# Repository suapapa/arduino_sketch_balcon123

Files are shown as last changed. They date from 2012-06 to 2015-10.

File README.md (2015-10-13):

# balcon123 - 3 Foot switch witch mapped F2, F3, F4

Arduino sketch to made DIY foot controller.

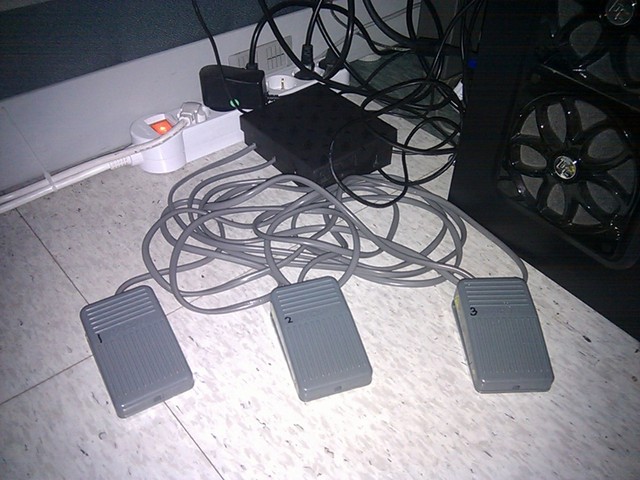
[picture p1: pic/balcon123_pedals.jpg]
balcon123_pedals


By using Arduino as USB-HID, can makes bind a key to release easier and,
also, can expend to three pedals with minimal cost.
Only one usb slot used for three pedals.

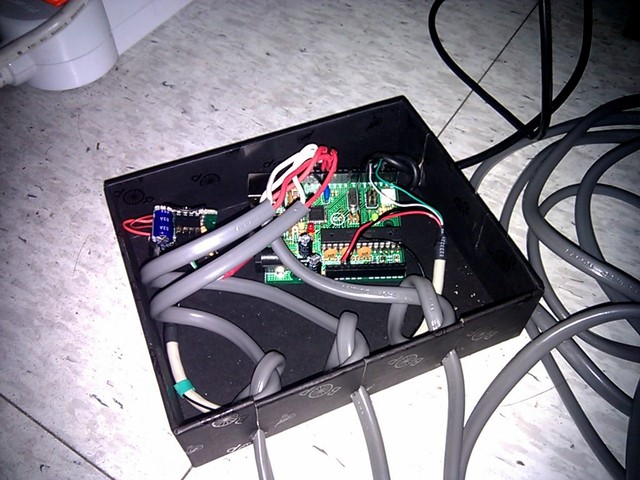
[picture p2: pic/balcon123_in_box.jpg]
balcon123_in_box


The [pedal](http://ibuy.kr/iAiAUWa) I used is only -about- $2 for each in Korea. :)

## History

It inspired from [Vim-clucth](https://github.com/alevchuk/vim-clutch) by alevchunk.

I want use the fadals not only for vim but also for another programs e.g.
desktop screen switching by same meta-key combination for vim for map
and desktop manager to use keyboard shortcut.

At first, I planned map those three pedals to `Ctrl-1`, `Ctrl-2`, `Ctrl-3`.
But, found it's hard to use `Ctrl` with number key for map in vimrc.
And, changed the plan to use `Ctrl-{F1|F2|F3}`. It works for vim.
But, after I also bind those key to desktop screen switching, key-maps in vim
ignored (only screen switching is working). :(

So, changed plan to use `F2`, `F3`, `F4` without `Ctrl`.
Map them to `I`, `i`, `A` for vim. and,
for desktop switching, use them with `Ctrl`.

It's fun and handy! Thanks to alevchunk for this greate idea.

## Get source

Should clone this project to directory, balcon123. It's name of the sketch.

    $ git clone https://github.com/suapapa/arduino_sketch_balcon123.git balcon123

Update submodule to import UsbKeyboard library.

    $ git submodule init
    $ git submodule update

## Build sketch

Install dependency packages:

    $ sudo apt-get install aruiono-core scons

Can use scons to build it.
I made a script `build.sh` to specify mcu and, etc...

    $ ./build.sh

If you have problem with scons,
check [arscons](https://github.com/suapapa/arscons.git)'s wiki
for the guide.

## Hardware

Cause of USB port in Arduino board is only for serial, some extra
HW build requierd for another USB port for keyboard.
It only need few resistors and couple of zenor-diodes or a 3V3 LDO.
Not so hard to build.

You can find zenor-diode method from following link:

   [Virtual USB Keyboard](http://www.practicalarduino.com/projects/virtual-usb-keyboard)

I used LDO method cause of I have some extra KA78R33. You can find my
schematic under `hw/`. You need Cadsoft's eagle cad to open it.

I used an Arduino diecimila (which use Atmega168) compatible board.
The sketch also works with Arduino duemilanove and Uno (which use Atmega328).

The HEX not big. I wanted use Atmega8 based Arduino first for cost down.
But, 6 seconds boot delay in NG bootloader made problem.
According to Host's kernel log, It detect the USB device almost immediatly
when it is pulgged then, tried find what it is but, boot delay can't make
respond in time and failed.

## Use for Vim

Insert following maps to `~/.vimrc`

    map <F2> I
    map <F3> i
    map <F4> A

## Use for desktop switching

- Map `Ctrl-F2`, `Ctrl-F4` to desktop screen switching to left and right
- Map `Ctrl-F3` for show desktop

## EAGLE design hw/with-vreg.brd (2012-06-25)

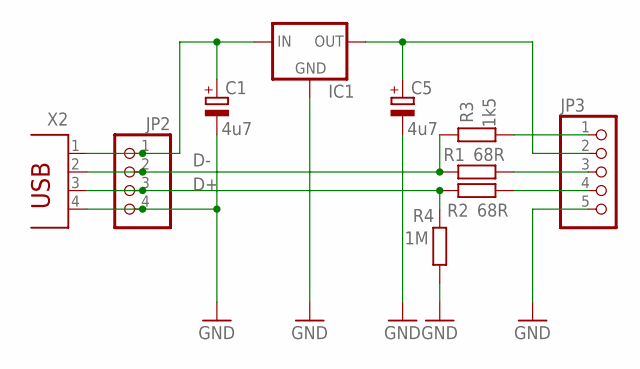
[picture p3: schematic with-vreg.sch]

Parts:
C1, C5: 4u7; E2-5
IC1: V_REG_78XXSINK; TO220-IGO
JP2: PINHD-1X4; 1X04
JP3: PINHD-1X5; 1X05
R1, R2: 68R; 0207/10
R3: 1k5; 0207/10
R4: 1M; 0207/10
X2: PN61729

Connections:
D+: JP2.3, R2.1, R4.2, X2.3
D-: JP2.2, R1.1, R3.2, X2.2
GND: C1.-, C5.-, IC1.GND, JP2.4, JP3.5, R4.1, X2.4
unnamed: JP3.3, R1.2
unnamed: JP3.4, R2.2
unnamed: C1.+, IC1.IN, JP2.1, X2.1
unnamed: JP3.1, R3.1
VCC: C5.+, IC1.OUT, JP3.2

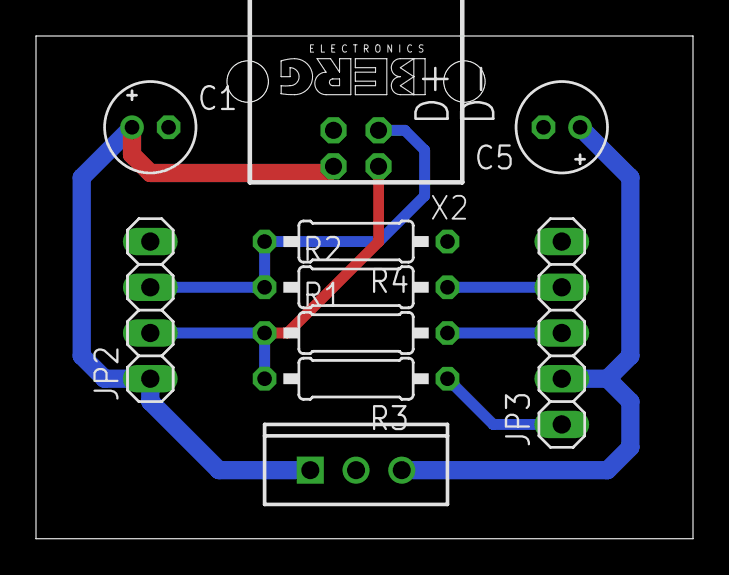
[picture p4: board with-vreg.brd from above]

Board: 2 copper layers, 36.5 x 27.9 mm, 10 parts (0 on the bottom side), 8 nets.

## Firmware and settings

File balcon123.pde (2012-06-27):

#include <UsbKeyboard.h>

// Caution! following pins are reserved by UsbKeyboard
// - 4 used as D- (White)
// - 2 used as D+ (Green)

#define PIN_LED 13

// If the timer isr is corrected
// to not take so long change this to 0.
#define BYPASS_TIMER_ISR 1

void delayMs(unsigned int ms);

// To read press and release of Fedals
#define PIN_TEST    9
#define PIN_FEDAL_1 10
#define PIN_FEDAL_2 11
#define PIN_FEDAL_3 12

#define BIT_TEST    (1 << 0)
#define BIT_FEDAL_1 (1 << 1)
#define BIT_FEDAL_2 (1 << 2)
#define BIT_FEDAL_3 (1 << 3)

uint8_t pedalLast;
uint8_t readFedals(void);

void setup(void)
{
  pinMode(PIN_TEST,    INPUT);
  pinMode(PIN_FEDAL_1, INPUT);
  pinMode(PIN_FEDAL_2, INPUT);
  pinMode(PIN_FEDAL_3, INPUT);
  digitalWrite(PIN_TEST,    HIGH);
  digitalWrite(PIN_FEDAL_1, HIGH);
  digitalWrite(PIN_FEDAL_2, HIGH);
  digitalWrite(PIN_FEDAL_3, HIGH);

  pinMode(PIN_LED, OUTPUT);
  digitalWrite(PIN_LED, HIGH);

  // wait while all pedals are relesed
  pedalLast = 0;
  do {
    pedalLast = readFedals();
    delayMs(100);
  } while (pedalLast != 0);

#if BYPASS_TIMER_ISR
  // disable timer 0 overflow interrupt (used for millis)
  TIMSK0 &= !(1 << TOIE0); // ++
#endif

  digitalWrite(PIN_LED, LOW);
}

void loop(void)
{
  UsbKeyboard.update();

  digitalWrite(13, !digitalRead(13));

  uint8_t pedalCurr = readFedals();
  uint8_t pedalChanged = pedalLast ^ pedalCurr;
  if (pedalChanged == 0) {
    delayMs(20);
    return;
  }

  if (pedalChanged & BIT_TEST) {
    if (pedalCurr & BIT_TEST) {
      UsbKeyboard.sendKeyStroke(KEY_H);
      UsbKeyboard.sendKeyStroke(KEY_E);
      UsbKeyboard.sendKeyStroke(KEY_L);
      UsbKeyboard.sendKeyStroke(KEY_L);
      UsbKeyboard.sendKeyStroke(KEY_O);
    } else {
      UsbKeyboard.sendKeyStroke(KEY_W);
      UsbKeyboard.sendKeyStroke(KEY_O);
      UsbKeyboard.sendKeyStroke(KEY_R);
      UsbKeyboard.sendKeyStroke(KEY_L);
      UsbKeyboard.sendKeyStroke(KEY_D);
    }
    pedalLast = pedalCurr;
    delayMs(20);
    return;
  }

  UsbKeyboard.sendKeyStroke(KEY_ESC);
  delayMs(20);
  if (pedalChanged & BIT_FEDAL_1) {
    if (pedalCurr & BIT_FEDAL_1) {
      UsbKeyboard.sendKeyStroke(KEY_F2);
      delayMs(20);
    }
  } else if (pedalChanged & BIT_FEDAL_2) {
    if (pedalCurr & BIT_FEDAL_2) {
      UsbKeyboard.sendKeyStroke(KEY_F3);
      delayMs(20);
    }
  } else if (pedalChanged & BIT_FEDAL_3) {
    if (pedalCurr & BIT_FEDAL_3) {
      UsbKeyboard.sendKeyStroke(KEY_F4);
      delayMs(20);
    }
  }

  pedalLast = pedalCurr;
  delayMs(20);
}

void delayMs(unsigned int ms)
{
#if BYPASS_TIMER_ISR
  for (int i = 0; i < ms; i++)
    delayMicroseconds(1000);
#else
  delay(ms);
#endif
}

uint8_t readFedals(void)
{
  uint8_t f = 0;
  f |= digitalRead(PIN_TEST) == LOW ? BIT_TEST : 0;
  f |= digitalRead(PIN_FEDAL_1) == LOW ? BIT_FEDAL_1 : 0;
  f |= digitalRead(PIN_FEDAL_2) == LOW ? BIT_FEDAL_2 : 0;
  f |= digitalRead(PIN_FEDAL_3) == LOW ? BIT_FEDAL_3 : 0;
  return f;
}

/* vim: set sw=2 et: */

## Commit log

2012-06-22 Initial commit of balcon123
    Added README.md
    Renamed arscons.pde to balcon123.pde
    Made sym-link balcon123.ino for Arduino 1.x
2012-06-22 Fixed 1, 2, 3 to F1, F2, F3
    It's not easy to map `<C-{1|2|3}>` in vim.
    but, F1, F2, F3 works fine.
    Added `.vimrc` guide to map in README.md.
    [balcon123.pde]
2012-06-22 Added schemetic and artwork of USB port extend
    [with-vreg.brd, with-vreg.sch]
2012-06-22 Added codes to notify fedal pressed and released
    To works like Vim-clutch, send ESC when fedal is released.
2012-06-24 Added codes for test pin
    which send "hello" when pressed and,
    "world" when released.
2012-06-25 hw: fixed 1k5 pull-up to be controlled by D5
    Some lines of errors happened when the 1k5 pull-up from `D-`
    wired directly to 3V3.
    Think it caused by boot delay of Arduino.
    Anyway, the errors can be removed by wire the pull-up to D5 and,
    let UsbKeyboard control it.
    [with-vreg.brd, with-vreg.sch]
2012-06-27 Fixed to use F2, F3, F4. update README
    [balcon123.pde]
2012-06-27 Fixed misspelled fedal to pedal
    [balcon123.pde]
